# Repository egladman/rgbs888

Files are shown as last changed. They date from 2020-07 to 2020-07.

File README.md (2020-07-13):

# rgbs888

Passive 24-bit RGBs adapter for Raspberry-Pi B+

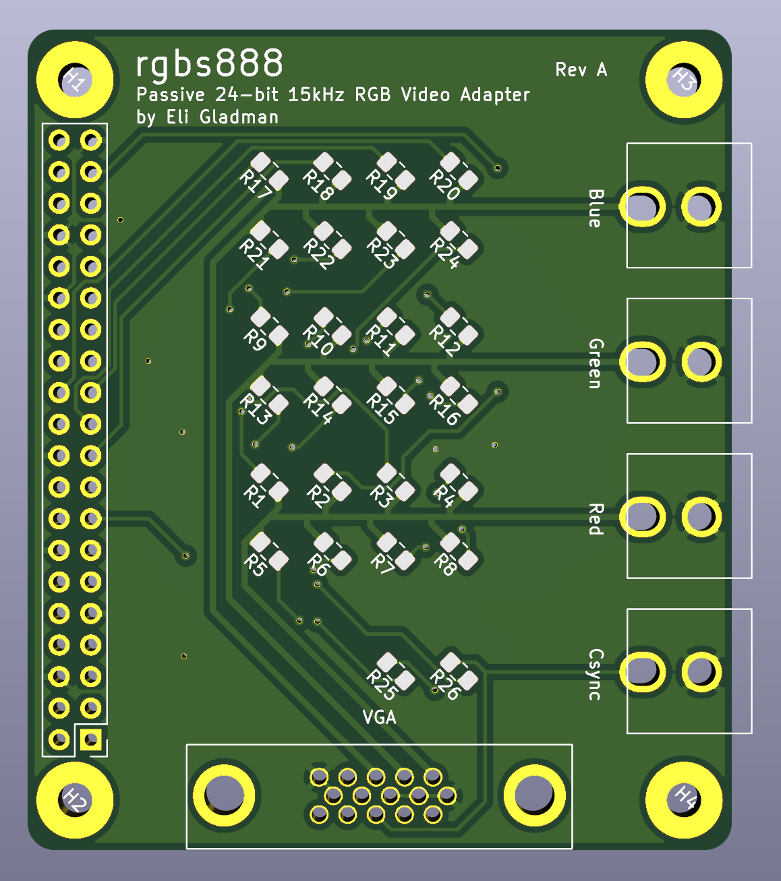
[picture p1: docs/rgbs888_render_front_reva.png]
Rev A Front

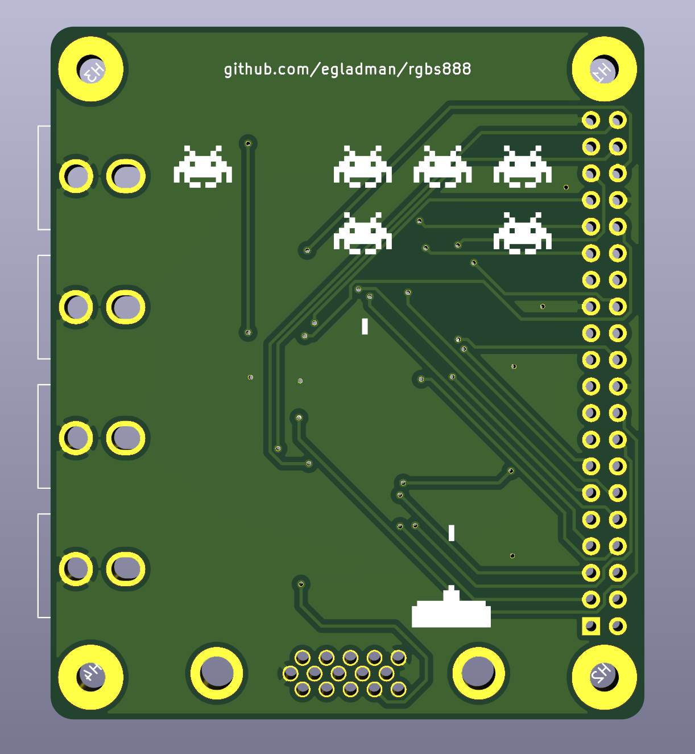
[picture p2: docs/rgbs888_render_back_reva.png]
Rev A Back


## Bill of Materials
- 1 2x20 2.5mm Female Header
- 4 RCA right angle female pcb mount connectors
- 1 DB15 female connector *Optional*
- 1 120 ohm 0805 resistor *We don't care about the tolerance as much, so 5% would be sufficient*
- 3 549 ohm 0805 1% tolerance resistor
- 3 1.1K ohm 0805 1% tolerance resistor
- 3 2.21K ohm 0805 1% tolerance resistor
- 3 4.42K ohm 0805 1% tolerance resistor
- 3 8.87K ohm 0805 1% tolerance resistor
- 3 17.8K ohm 0805 1% tolerance resistor
- 3 35.7K ohm 0805 1% tolerance resistor
- 3 71.5K ohm 0805 1% tolerance resistor

```
MOUSER PART NUMBERS
========================

Connectors
806-KLPX-0848A-2-B
523-7HDE15SDH4RHNVGA

Resistors
667-ERJ-6GEYJ121V
652-CR0805FX-5490ELF
603-RC0805FR-131K1L
603-RC0805FR-072K21L
667-ERJ-6ENF4421V
667-ERJ-6ENF8871V
667-ERJ-6ENF1782V
667-ERJ-6ENF3572V
667-ERJ-6ENF7152V
```

## License

Copyright © 2020 Eli Gladman 

This document and the related databases are free: you can redistribute it and/or modify it under the terms of the GNU General Public License as published by the Free Software Foundation, either version 3 of the License, or any later version. This document and the related databases are distributed in the hope that it will be useful, but WITHOUT ANY WARRANTY; without even the implied warranty of MERCHANTABILITY or FITNESS FOR A PARTICULAR PURPOSE. See the GNU General Public License for more details. You should have received a copy of the GNU General Public License along with this database. If not, see http://www.gnu.org/licenses/

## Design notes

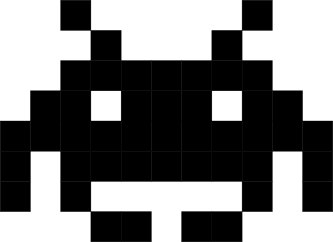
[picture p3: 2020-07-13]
assets/alien.png

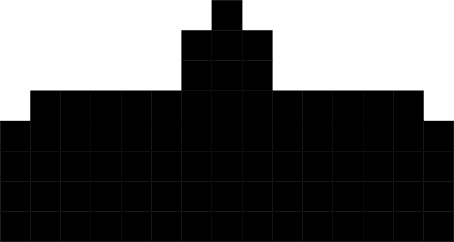
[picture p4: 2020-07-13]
assets/cannon.png

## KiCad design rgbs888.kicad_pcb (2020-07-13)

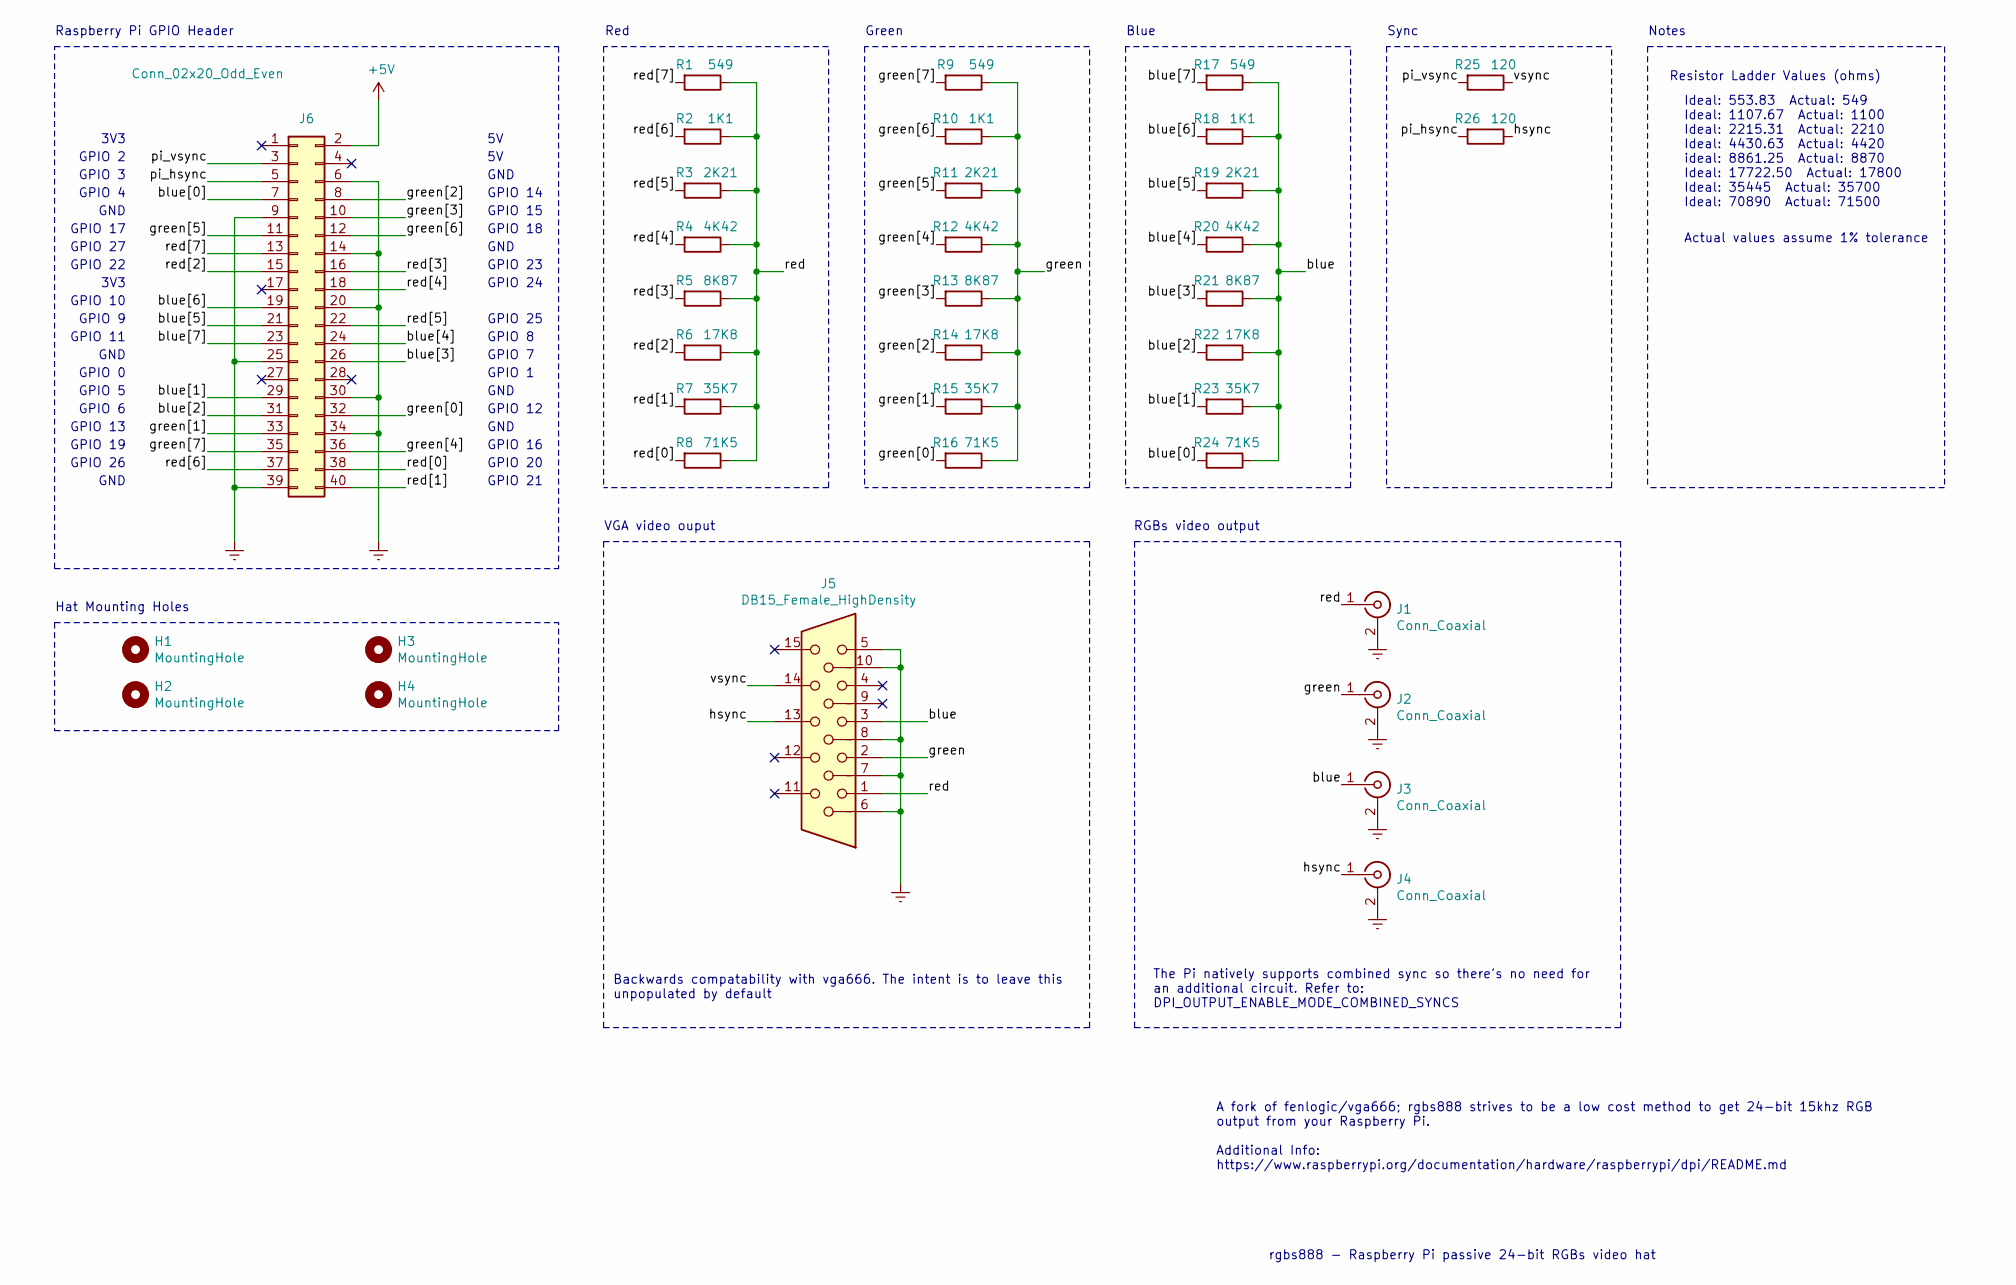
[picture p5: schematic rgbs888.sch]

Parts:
H1, H2, H3, H4: MountingHole; Pi_Hat_Mounting_Hole
J1, J2, J3, J4: Conn_Coaxial; RCA_Female_THT-1_Horizontal
J5: DB15_Female_HighDensity; DB15_Female_THT
J6: Conn_02x20_Odd_Even; PinHeader_2x20_P2.54mm_Vertical
R1, R9, R17: 549; R_0805_2012Metric_Pad1.15x1.40mm_HandSolder
R2, R10, R18: 1K1; R_0805_2012Metric_Pad1.15x1.40mm_HandSolder
R3, R11, R19: 2K21; R_0805_2012Metric_Pad1.15x1.40mm_HandSolder
R4, R12, R20: 4K42; R_0805_2012Metric_Pad1.15x1.40mm_HandSolder
R5, R13, R21: 8K87; R_0805_2012Metric_Pad1.15x1.40mm_HandSolder
R6, R14, R22: 17K8; R_0805_2012Metric_Pad1.15x1.40mm_HandSolder
R7, R15, R23: 35K7; R_0805_2012Metric_Pad1.15x1.40mm_HandSolder
R8, R16, R24: 71K5; R_0805_2012Metric_Pad1.15x1.40mm_HandSolder
R25, R26: 120; R_0805_2012Metric_Pad1.15x1.40mm_HandSolder

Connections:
+5V: J6.2
/blue: J3.1 (In), J5.3, R17.1, R18.1, R19.1, R20.1, R21.1, R22.1, R23.1, R24.1
/blue[0]: J6.7, R24.2
/blue[1]: J6.29, R23.2
/blue[2]: J6.31, R22.2
/blue[3]: J6.26, R21.2
/blue[4]: J6.24, R20.2
/blue[5]: J6.21, R19.2
/blue[6]: J6.19, R18.2
/blue[7]: J6.23, R17.2
/green: J2.1 (In), J5.2, R9.1, R10.1, R11.1, R12.1, R13.1, R14.1, R15.1, R16.1
/green[0]: J6.32, R16.2
/green[1]: J6.33, R15.2
/green[2]: J6.8, R14.2
/green[3]: J6.10, R13.2
/green[4]: J6.36, R12.2
/green[5]: J6.11, R11.2
/green[6]: J6.12, R10.2
/green[7]: J6.35, R9.2
/hsync: J4.1 (In), J5.13, R26.1
/pi_hsync: J6.5, R26.2
/pi_vsync: J6.3, R25.2
/red: J1.1 (In), J5.1, R1.1, R2.1, R3.1, R4.1, R5.1, R6.1, R7.1, R8.1
/red[0]: J6.38, R8.2
/red[1]: J6.40, R7.2
/red[2]: J6.15, R6.2
/red[3]: J6.16, R5.2
/red[4]: J6.18, R4.2
/red[5]: J6.22, R3.2
/red[6]: J6.37, R2.2
/red[7]: J6.13, R1.2
/vsync: J5.14, R25.1
Earth: J1.2 (Ext), J2.2 (Ext), J3.2 (Ext), J4.2 (Ext), J5.5, J5.6, J5.7, J5.8, J5.10, J6.6, J6.9, J6.14, J6.20, J6.25, J6.30, J6.34, J6.39

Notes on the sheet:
rgbs888 - Raspberry Pi passive 24-bit RGBs video hat
RGBs video output
Red
Raspberry Pi GPIO Header
Hat Mounting Holes
GPIO 21
GPIO 20
GPIO 16
GPIO 12
GPIO 7
GPIO 8
GPIO 25
GPIO 24
GPIO 23
GPIO 18
GPIO 15
GPIO 14
GND
GPIO 1
GPIO 26
GPIO 19
GPIO 13
GPIO 6
GPIO 5
GPIO 0
GPIO 11
GPIO 9
GPIO 10
3V3
GPIO 22
GPIO 27
GPIO 17
GPIO 4
GPIO 3
GPIO 2
Green
Blue
Actual values assume 1% tolerance
The Pi natively supports combined sync so there's no need for an additional circuit. Refer to: DPI_OUTPUT_ENABLE_MODE_COMBINED_SYNCS
Sync

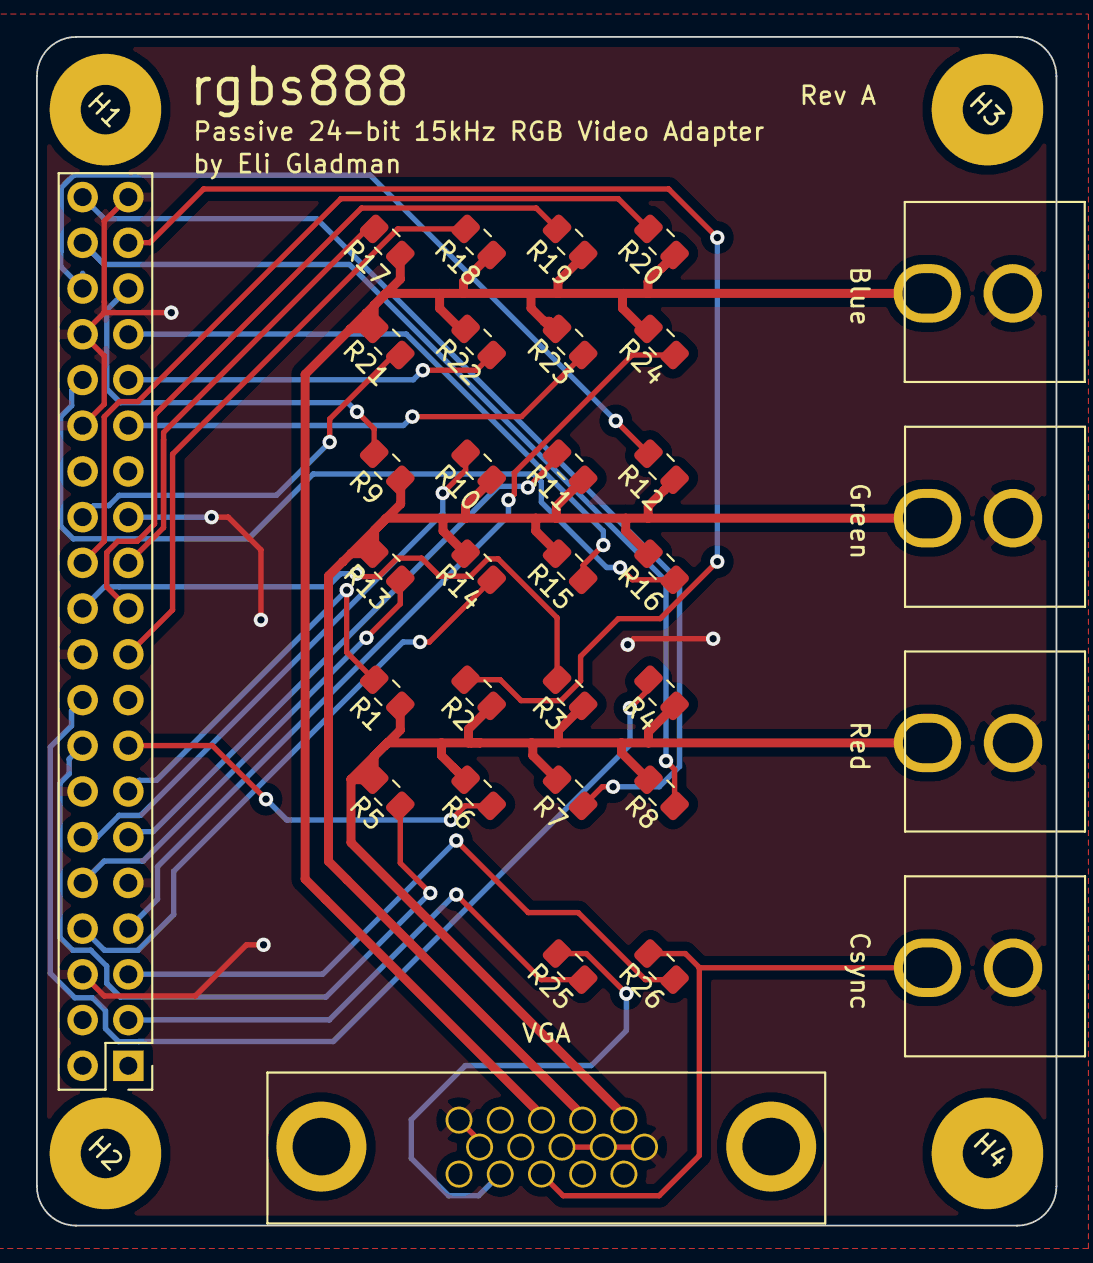
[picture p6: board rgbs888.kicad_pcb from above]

Board: 2 copper layers, 56.6 x 66.0 mm, 36 parts (0 on the bottom side), 32 nets.
